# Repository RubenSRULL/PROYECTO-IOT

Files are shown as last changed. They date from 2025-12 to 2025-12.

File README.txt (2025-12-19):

Rubén Sahuquillo Redondo

Estructura del proyecto:
- Carpeta src: contiene el código desarrollado en Python
- Carpeta esp32: contiene los códigos de las ESP32
- Carpeta fig: contiene las figuras y esquemas desarrollados
- Carpeta cad: contiene el esquema del circuito
- Carpeta frizting: contiene el esquema electrónico elaborado en Fritzing

Enlace al repositorio con todo el proyecto: https://github.com/RubenSRULL/PROYECTO-IOT.git

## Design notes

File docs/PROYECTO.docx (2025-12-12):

# PROYECYO IOT:

# CONTROL DE UNA BOMBA DE DESPLAZAMIENTO POSITIVO EN UN SISTEMA DE TRASIEGO DE CRUDO Y COMBUSTIBLES

Rubén Sahuquillo Redondo

alu0101387451@ull.edu.es

Curso 2025 / 2026

# 1. INTRODUCCIÓN

## 1.1. INTRODUCCIÓN

- Este proyecto propone el diseño de un sistema para el control de una bomba de desplazamiento positivo utilizada en el trasiego de combustibles, accionada por un motor trifásico de corriente alterna.
- En este tipo de instalaciones, el arranque del motor se realiza normalmente mediante el método estrella–triángulo. Sin embargo, la conmutación suele ejecutarse por temporización fija, lo que no siempre coincide con la velocidad real del motor ni con las condiciones hidráulicas del sistema. Esta situación puede generar sobrecorrientes, golpes de presión y arranques ineficientes, especialmente cuando la demanda de caudal o presión varía.
- Para resolver este problema, el proyecto incorpora un sensor Hall que mide la velocidad del motor en tiempo real, determinando el momento óptimo para la transición de estrella a triángulo. Además, el sistema cuenta con conectividad IoT, lo que permite monitoreo, registro y supervisión remota, mejorando la seguridad y eficiencia operativa del trasiego de combustibles.

## 1.2. SISTEMA PROPUESTO

- El sistema propuesto consiste en un controlador electrónico, integrado en el microcontrolador ESP 32 WROOM 32, encargado de gestionar el arranque del motor. Durante la puesta en marcha, el sistema de sensado (conformado por el microcontrolador WEMOS D1 R32 y un sensor de efecto Hall) mide la velocidad del eje y envía los datos al microcontrolador de control. Cuando el motor alcanza una velocidad predefinida (un 80% de su velocidad nominal), el controlador activa la conmutación del contacto estrella al contacto triángulo.
- Además, el sistema incorpora conectividad IoT que permite:
  - Monitorizar en tiempo real la velocidad del motor y el estado del arranque
  - Detener y cambiar el sentido de giro de la bomba en cualquier instante

## 1.3. OBJETIVOS

- Objetivo general
  - Implementar un sistema de arranque inteligente para un motor AC que realice la conmutación estrella–triángulo basándose en la velocidad real del motor, utilizando un sensor Hall e integración IoT.
- Objetivos específicos
  - Medir la velocidad del motor durante el arranque mediante un sensor Hall.
  - Integrar el sistema a una plataforma IoT que permita un control efectivo

## 1.4. ALCANCE

- En base a los objetivos y al Proyecto propuesto, el alcance de este proyecto incluye:
  - Implementación y programación del sistema de medición de velocidad mediante sensor de efecto Hall.
  - Desarrollo del controlador encargado de gestionar la conmutación estrella–triángulo en el arranque, parada y cambio de sentido de giro
  - Integración básica con una plataforma IoT para visualización de datos y control de arranque
- El proyecto no implementa un lazo de control cerrado para la regulación de velocidad

# 2. MARCO TEÓRICO

## 2.1. BOMBA DE DESPLAZAMIENTO POSITIVO

- Una bomba de desplazamiento positivo (DP) es un tipo de bomba que traslada un volumen fijo de fluido (generalmente fluidos viscosos) en cada ciclo o rotación, independientemente de la presión del sistema, generando un caudal constante. Algunos tipos de bombas DP se muestran en la figura
- Estas bombas funcionan capturando el fluido en un compartimento cerrado y desplazándolo hacia la salida mediante el movimiento de elementos mecánicos como engranajes, lóbulos, tornillos, pistones o diafragmas.
- Estas bombas se caracterizan por:
  - Manejar un caudal constante, aunque varíe la presión del sistema.
  - Capacidad de manejar fluidos viscosos, abrasivos o cargados de sólidos.
  - Algunas diseñadas para flujo reversible, permitiendo invertir la dirección del líquido cuando el proceso lo requiere.

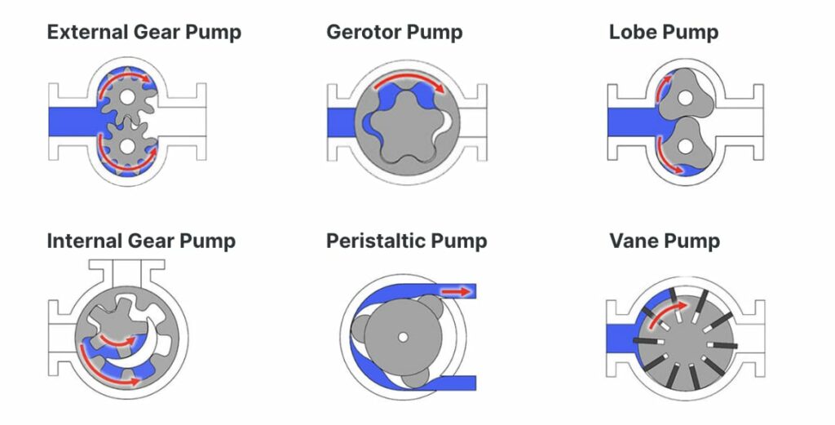
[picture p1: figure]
Positive Displacement Pump - what is positive displacement pump - Vacculex

Ilustración 1: Algunos tipos y mecanismos comunes empleados en bombas de desplazamiento positivo

## 2.2. MOTOR DE INDUCCIÓN TRIFÁSICO: JAULA DE ARDILLA

- Un motor de inducción trifásico es una máquina eléctrica rotativa ampliamente utilizada en aplicaciones industriales debido a su robustez, bajo mantenimiento y buena relación costo-prestaciones.
- Su funcionamiento se basa en el principio de inducción electromagnética: al aplicar un sistema trifásico de tensiones en el estator, se genera un campo magnético giratorio que induce corrientes en el rotor, produciendo el par motor.
- La velocidad del motor depende de la frecuencia de la red y del número de polos del estator. Al tratarse de una máquina asíncrona, el rotor gira a una velocidad ligeramente inferior a la velocidad síncrona
- Estos motores deben arrancar de forma controlada para evitar sobrecorrientes y esfuerzos mecánicos, especialmente cuando la carga hidráulica es variable.

## 2.3. ARRANQUE ESTRELLA - TRIÁNGULO

- El arranque estrella–triángulo es un método convencional para reducir la corriente inicial de los motores trifásicos. Consiste en conectar los devanados del estator inicialmente en configuración estrella, lo que reduce la tensión aplicada a cada fase y, por tanto, la corriente y el par motor. Después de un intervalo determinado, los devanados se reconectan en configuración triángulo, permitiendo que el motor reciba la tensión nominal y alcance su par y velocidad de operación.
- En este proyecto, la conmutación se realiza según la velocidad real del motor, eliminando la dependencia del tiempo y optimizando el proceso.

## 2.4. SENSOR HALL

- Un sensor Hall es un dispositivo que detecta la presencia de un campo magnético y genera una señal eléctrica proporcional. Su funcionamiento se basa en el efecto Hall, fenómeno que produce una variación de tensión cuando un conductor atravesado por corriente se expone a un campo magnético perpendicular (este efecto se muestra en la figura 2)
- Cuando se coloca un imán adherido al eje del motor, el sensor detecta cada paso del imán y produce un pulso. Contando estos pulsos en un intervalo conocido, es posible calcular la velocidad de giro.
- Los sensores Hall son adecuados para entornos industriales debido a su fiabilidad, su bajo consumo y su capacidad para medir sin contacto mecánico.
- En este proyecto se emplea este sensor para determinar el instante preciso en el que el motor alcanza la velocidad necesaria para realizar la transición de estrella a triángulo.

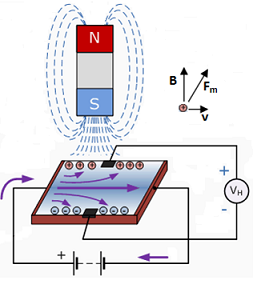
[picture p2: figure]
Electromagnetismo. Efecto Hall

Ilustración 2: Efecto Hall

# 3. DESARROLLO

## 3.1. MEDICIÓN DE VELOCIDADES. VALIDACIÓN

- La arquitectura implementada para la medición de velocidades consiste en:
  - Acoplamiento de un imán de neodimio al eje del motor de inducción.
  - Colocación del sensor hall en posición óptima, es decir, aquella posición que permita la detección del campo magnético generado por el imán sin comprometer las lecturas o integridad del sensor
  - Activar lectura de interrupciones en un pin del Wemos D1 R32 por un tiempo determinado. Cada vez que el imán pase frente al sensor hall, este generará un pulso, produciendo una interrupción.
  - En ficha interrupción se realizará el conteo de pulsos detectado (o equivalentemente, contar cuántas veces pasa el imán frente al sensor). Contar los pulsos producidos en un tiempo determinado (1 segundo) y dividir entre 2 (ya que se producen 2 pulsos por revolución)
  - Dividir número de pulsos entre tiempo de medición

ω=(revoluciones)/(tiempo) [Hz]

  - Reiniciar contador e interrupciones para permitir la obtención de nuevas mediciones
- Las mediciones de velocidad fueron validadas empleando el controlador de velocidad ATV320 (figura 3). Tanto con el controlador ATV320 con el sensor hall se obtuvieron lecturas similares:

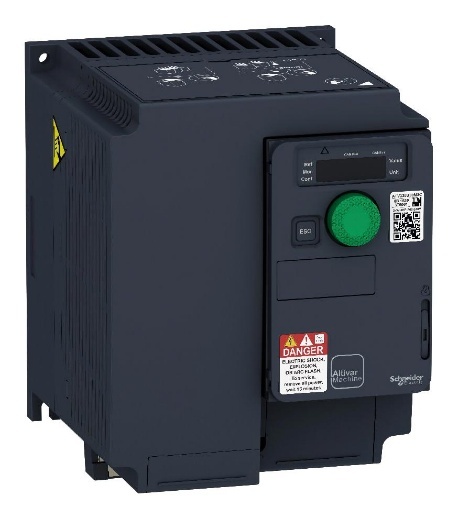
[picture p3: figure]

Ilustración 3: Controlador de velocidad ATV320, empleado para validar el sistema de medición

## 3.2. LÓGICA DE CONMUTACIÓN

### 3.2.1. CIRCUITO DE POTENCIA

- El circuito de potencia que alimenta al motor de inducción trifásico permite el cambio de sentido de giro (gestionado por los contactores KM1 Y KM2) además de la conmutación estrella – triángulo (gestionado por los contactores KM3 y KM4). Se incluye un guardamotor y un fusible como elementos de seguridad (ver figura 4)

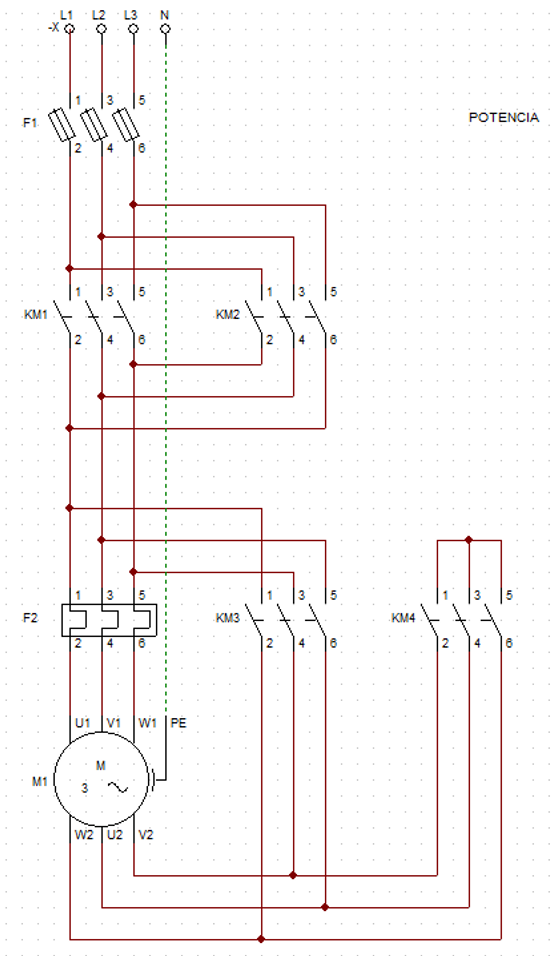
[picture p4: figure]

Ilustración 4: Circuito eléctrico de potencia

### 3.2.2. CIRCUITOS DE CONTROL

- El circuito que permite el accionamiento de los diferentes contactores de control del sistema está conformado por 4 relés que activan los diferentes contactores (esquema mostrado en la figura 5):
  - Los relés 1 y 2 activan las bobinas de los contactores KM1 y KM2 respectivamente con enclavamiento eléctrico, impidiendo que ambos contactores puedan estar activos a la vez. Este mecanismo permite seleccionar únicamente un sentido de giro
  - Los relés 3 y 4 activan las bobinas de los contactores KM3 y KM4 respectivamente con enclavamiento eléctrico, impidiendo que ambos contactores puedan estar activos a la vez. Este mecanismo permite configurar únicamente la conexión estrella o triángulo.
  - Como dispositivos de protección eléctrica se incluyen un fusible y un térmico F1 y F2. Además, como dispositivo de paro y control manual, se incluye un pulsador normalmente cerrado. En caso de ser presionado, abre el circuito de control, impidiendo el paso de corriente eléctrica a los contactores, deteniendo el motor. Como señal luminosa, se incluye un led de estado que indica la presencia de tensión en el sistema

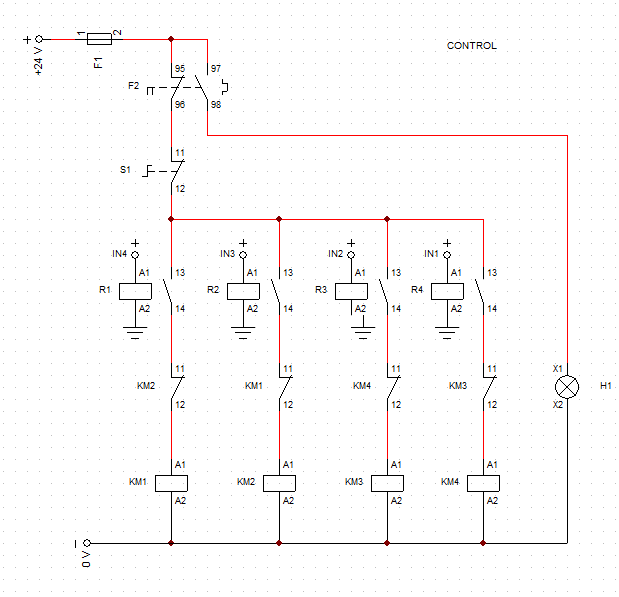
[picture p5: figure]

Ilustración 5: Circuito eléctrico de control

### 3.2.3. ELECTRÓNICA: SENSORES Y RELÉS

- El circuito electrónico (figura 6) consiste en 2 partes diferencias:
  - Circuito del sistema de sensado, conformado por:
    - Microcontrolador Wemos D1 R32, encargado de la medición de velocidad de rotación y publicación de esta por MQTT.
    - Módulo KY – 035 que integra un sensor Hall, empleado como sensor de velocidad
    - Condensador cerámico de 100 μF, conectado entre la señal de pulsos y tierra. Su finalidad es, junto a un filtro digital también programado, filtrar el ruido de lectura entre pulsos consecutivos
    - Pantalla LCD Hitachi 16x2 con módulo I2C
    - Batería de 9 V
  - Circuito del sistema de control, conformado por:
    - Microcontrolador ESP32 WROOM 32, encargado de alojar el servidor web, controlar tanto la secuencia de arranque como el sentido de giro del motor y de la lectura de velocidades publicadas
    - Módulo de control de relés AVR PIC, empleados para la activación de contactores

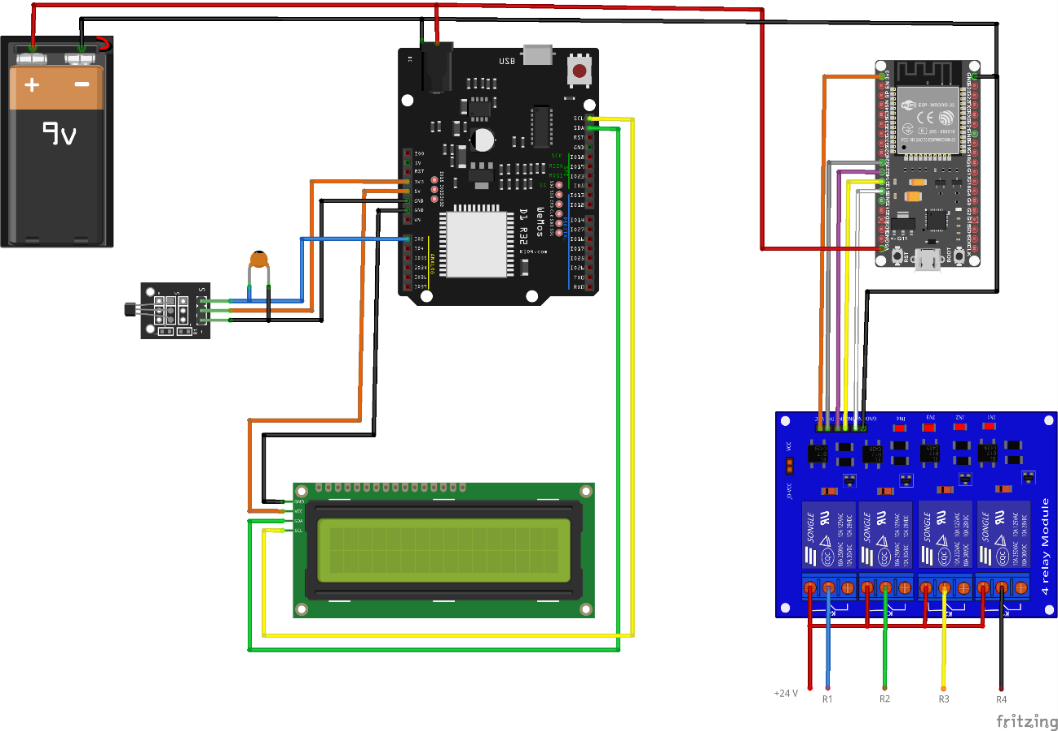
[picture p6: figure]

Ilustración 6: Circuito eléctrico de control de relés y sensado (elaborado en fritzing)

## 3.3. INTERFAZ WEB

- La interfaz web desarrollada actúa como el punto central de supervisión y control del sistema, permitiendo al usuario gestionar el funcionamiento del motor de manera remota desde cualquier dispositivo conectado a la misma red. Una vista de esta interfaz web se muestra en la figura 7.
- En primer lugar, la interfaz permite seleccionar el sentido de giro de la bomba (giro horario o antihorario) mediante comandos enviados al microcontrolador a través del servidor web integrado. También incorpora una opción de parada inmediata, asegurando que el motor pueda ser detenido en cualquier momento, incluso durante el proceso de arranque o transición entre configuraciones.
- La interfaz muestra información en tiempo real sobre la velocidad de rotación del motor en hercios (Hz). Esto permite al usuario conocer en todo momento el comportamiento dinámico del motor.
- La interfaz también refleja el estado actual del sistema, indicando si el motor se encuentra detenido, en giro horario, en giro antihorario o en fase de arranque. De esta forma, el operador puede supervisar desde una única vista tanto la condición mecánica del motor como el progreso del algoritmo de conmutación.

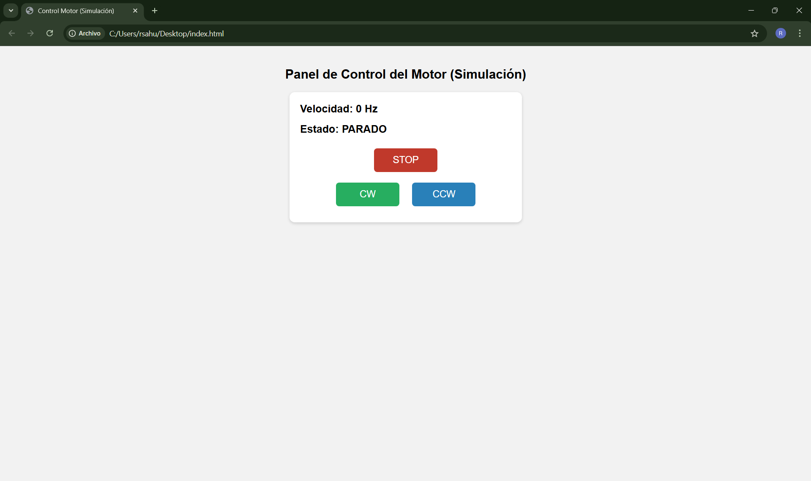
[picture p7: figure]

Ilustración 7: Vista de la interfaz web desarrollada

## 3.4. COMUNICACIONES MQTT

- El sistema utiliza el protocolo MQTT (Message Queuing Telemetry Transport) para intercambiar información entre los dos dispositivos principales:
  - WEMOS D1 R32 → encargado de leer el sensor Hall y enviar las RPM.
  - ESP32 WROOM 32 → encargado de procesar esa información y controlar los relés.
- Toda la comunicación está centralizada en un broker MQTT, alojado en el PC, que actúa como intermediario entre publicadores y suscriptores.
- MQTT funciona mediante tópicos, que son “canales” por donde se envían o reciben mensajes. Cada dispositivo puede ser:
  - Publicador (publisher) → Envía datos a un tópico.
  - Suscriptor (subscriber) → Recibe datos de un tópico

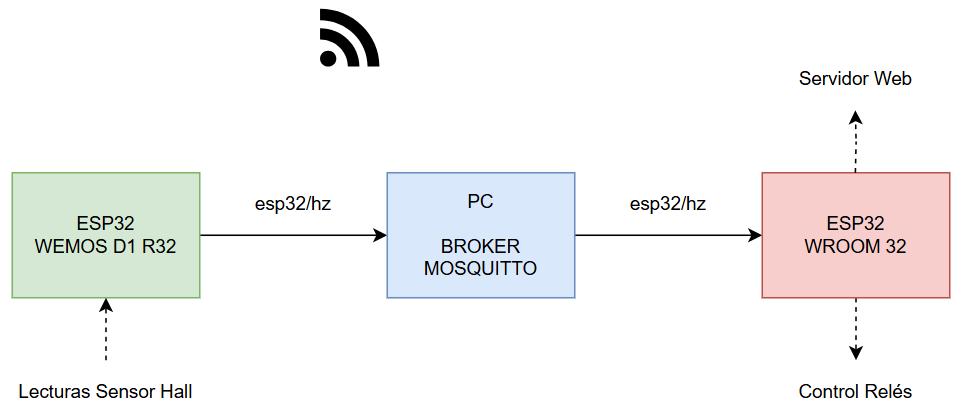
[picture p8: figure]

Ilustración 8: Esquema de comunicaciones MQTT implementado

# 4. CÓDIGOS DESARROLLADOS

## 4.1. CÓDIGO DEL MICROCONTROLADOR DE SENSADO (WEMOS D1 R32)

- Función de setup(): Esta función inicializa el programa. Se encarga de:
  - Inicializar el módulo WiFi.
  - Inicializar la comunicación MQTT.
  - Configurar interrupción para leer velocidad

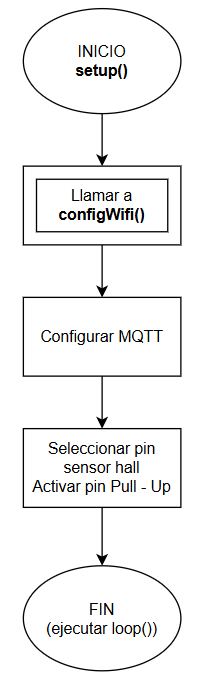
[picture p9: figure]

Ilustración 9: Flujograma del setup()

- Función de loop(): esta función se encarga de leer y calcular la velocidad de rotación del motor de forma periódica. Se encarga de:
  - Reestablecer la comunicación MQTT si esta se ha perdido
  - Mantener abierta la comunicación MQTT
  - Medir la velocidad de rotación del motor
  - Publicar mediciones por MQTT al tópico esp32/hz

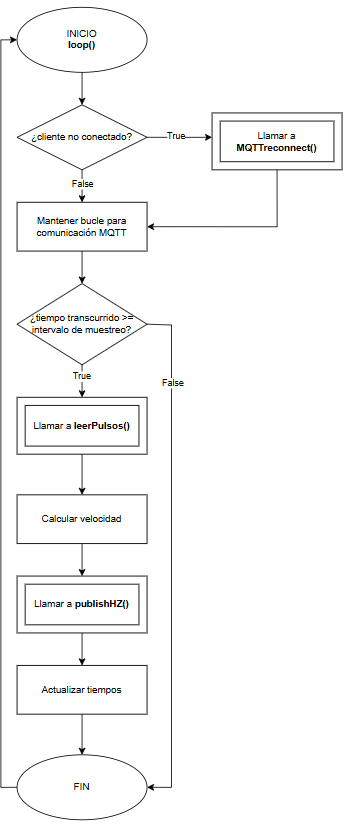
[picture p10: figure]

Ilustración 10: Flujograma del loop()

- Funciones llamadas en el setup():
  - Función configWifi(): Esta función permite establecer conexión WiFi y coenctarse a la red. Se encarga de:
    - Configurar comunicación Wifi en modo estación
    - Iniciar la conexión Wifi

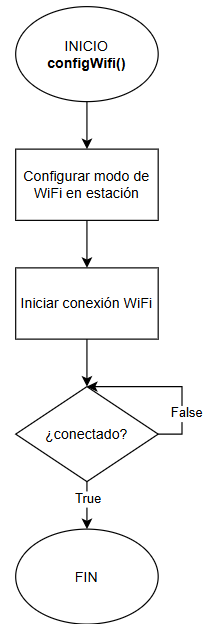
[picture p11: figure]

Ilustración 11: Flujograma función configWifi()

- Funciones llamadas en el loop()
  - Función leerPulsos(): Esta función permite leer los pulsos contabilizados de forma segura además de reiniciar el contador de pulsos, permitiendo obtener una nueva medición de velocidad

Ilustración 12: Flujograma función leerPulsos()

  - Función publishHZ(): Esta función permite publicar la velocidad calculada al tópico esp32/hz

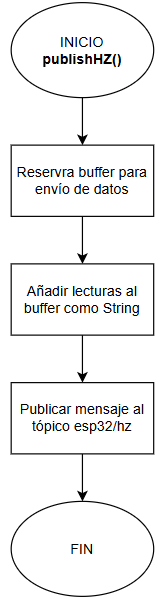
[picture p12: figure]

Ilustración 13: Función para publicar velocidad leída en hercios, publishHZ()

  - Función MQTTreconnect(): Esta función permite reconectar la conexión con el broker MQTT y/o wifi si alguna de estas se pierde

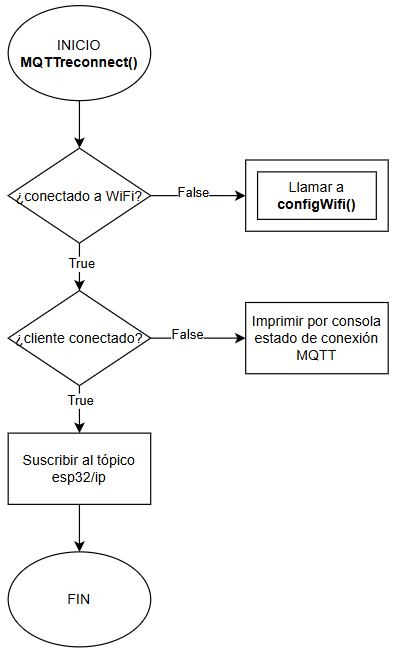
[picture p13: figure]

Ilustración 14: Función para reconectar con bróker MQTT, MQTTreconnect()

## 4.2. CÓDIGO DEL MICROCONTROLADOR DE CONTROL (ESP32 WROOM 32)

- Función setup(): Esta función inicializa el programa. Se encarga de:
  - Inicializar el módulo WiFi.
  - Inicializar la comunicación MQTT.
  - Inicializar servidor web

Ilustración 15: Flujograma del setup()

- Función loop(): esta función permite mantener activo el servidor web, así como el control del motor trifásico por medio de una máquina de estados (arranque, parada y sentido de giro). Se encarga de:
  - Reestablecer la comunicación MQTT si esta se ha perdido
  - Mantener abierta la comunicación MQTT
  - Mantener activo el servidor web
  - En función del estado actual del sistema, ejecutar la acción de control oportuna

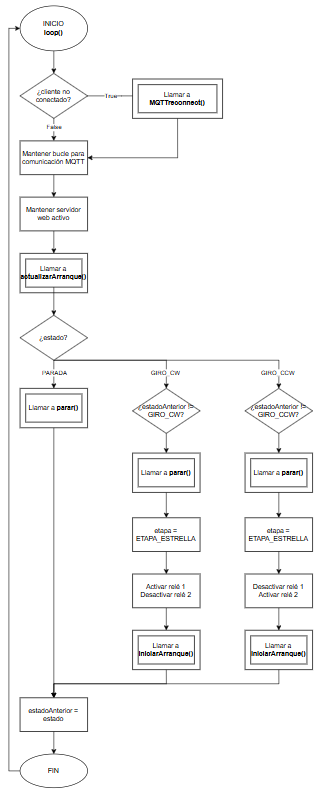
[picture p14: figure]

Ilustración 16: Flujograma del loop()

- Funciones llamadas en el setup()
  - Función configWifi(): Esta función permite establecer conexión Wifi y conectarse a la red. Se encarga de:
    - Configurar comunicación Wifi en modo estación
    - Iniciar la conexión Wifi

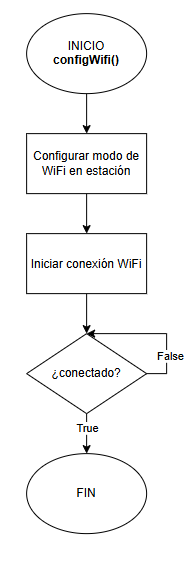
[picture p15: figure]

Ilustración 17: Flujograma de la función configWifi()

- Funciones llamadas en el loop()
  - Función MQTTreconnect(): Esta función permite reestablecer la conexión con el broker MQTT y/o Wifi si alguna de estas se pierde

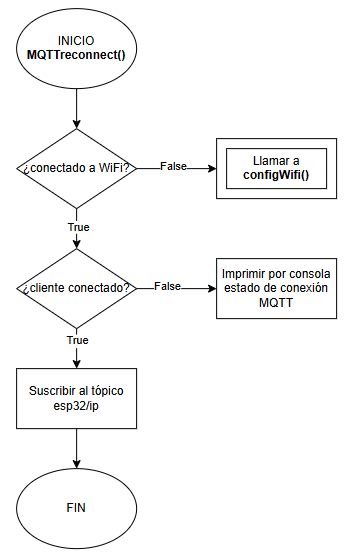
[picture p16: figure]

Ilustración 18: Flujograma de la función MQTTreconnect()

  - Función parar(): Esta función permite detener completamente el motor
  - Función iniciarArranque(): Esta función inicia la secuencia de arranque, realizando la conexión en estrella hasta que la velocidad leída sea superior al umbral establecido
  - Función actualizarArranque(): Esta función permite realizar la conmutación a triángulo una vez la velocidad leída es la adecuada

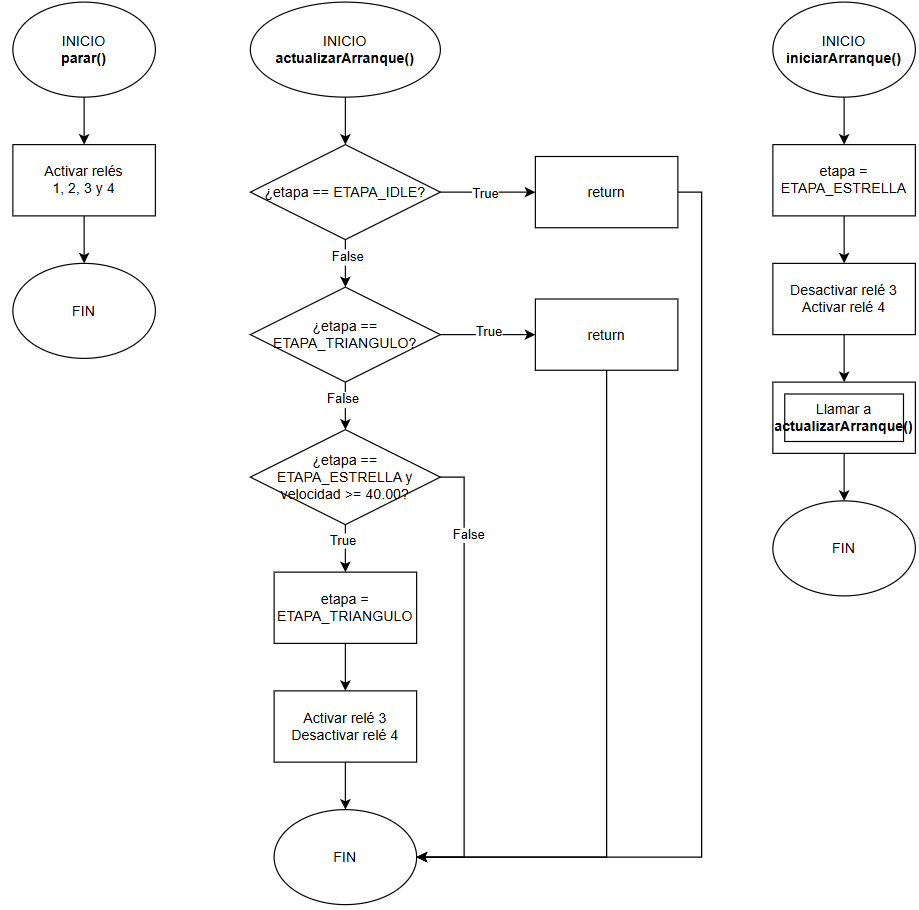
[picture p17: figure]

Ilustración 19: Flujogramas de las funciones parar(), actualizarArranque(), iniciarArranque()

- Función para generar página web generarPagina(): esta función define la interfaz web. Permite:
  - Definir el código HTML dentro de una variable String
  - Modificar textos HTML en función del estado actual del sistema y velocidad recibida por MQTT

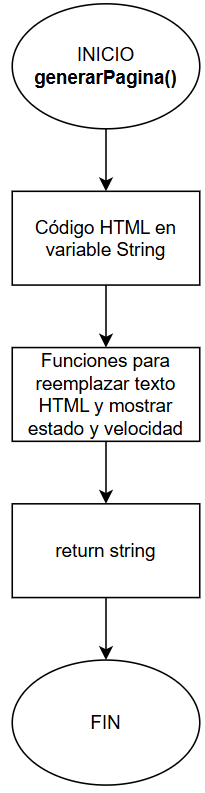
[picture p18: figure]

Ilustración 20: Flujograma con la función para generar la página web generarPagina()

- Función de Callback MQTT → callback(): Esta función es ejecutada cada vez que se recibe un mensaje por MQTT. Permite recibir las velocidades leídas desde el microcontrolador encargado de la adquisición de datos

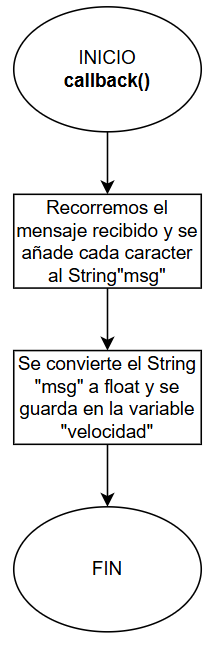
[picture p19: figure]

Ilustración 21: Función de callback, callback(). Se ejecuta cada vez que se recibe un mensaje MQTT

## 4.3. CÓDIGO PARA ARRANCAR BROKER MOSQUITTO

- Este script permite inicializar el bróker Mosquitto y cargar el fichero de configuración (.conf), evitando introducir comandos en consola, facilitando su inicialización
1. Se importan las librerías siguientes:
  a. os: facilita el manejo de ficheros
  b. subprocess: permite ejecutar comandos en consola desde el script
  c. time: permite el manejo de funciones de tiempo
2. Se indican las rutas tanto del ejecutable Mosquitto (.exe) y el fichero de configuración (.conf)
3. En “__main__” se llama a la función iniciar_broker()
4. Función iniciar_broker(): esta función arranca el proceso mosquitto.exe siempre que no esté activo en la lista de procesos activos. En caso de estar activo, mostrará un mensaje de confirmación y en caso de ocurrir un error, los mostrará por pantalla

import os

import subprocess

import time

mosquitto_path = r"C:\Program Files\mosquitto\mosquitto.exe"

mosquitto_conf = r"C:\Program Files\mosquitto\mosquitto.conf"

def iniciar_broker():

try:

procesos = os.popen('tasklist').read().lower()

if "mosquitto.exe" not in procesos:

subprocess.Popen(

f'"{mosquitto_path}" -v -c "{mosquitto_conf}"',

shell=True,

stdout=subprocess.DEVNULL,

stderr=subprocess.DEVNULL

)

print("Broker Mosquitto iniciado en segundo plano.")

time.sleep(3)

else:

print("Broker Mosquitto ya está ejecutándose.")

except Exception as e:

print(f"Error al iniciar el broker: {e}")

if __name__ == '__main__':

iniciar_broker()

# 5. ANEXOS

## 5.1. MICROCONTROLADOR: ESP32 – WROOM – 32

https://descubrearduino.com/esp32-modulo-esp32-wroom-gpio-pinout/

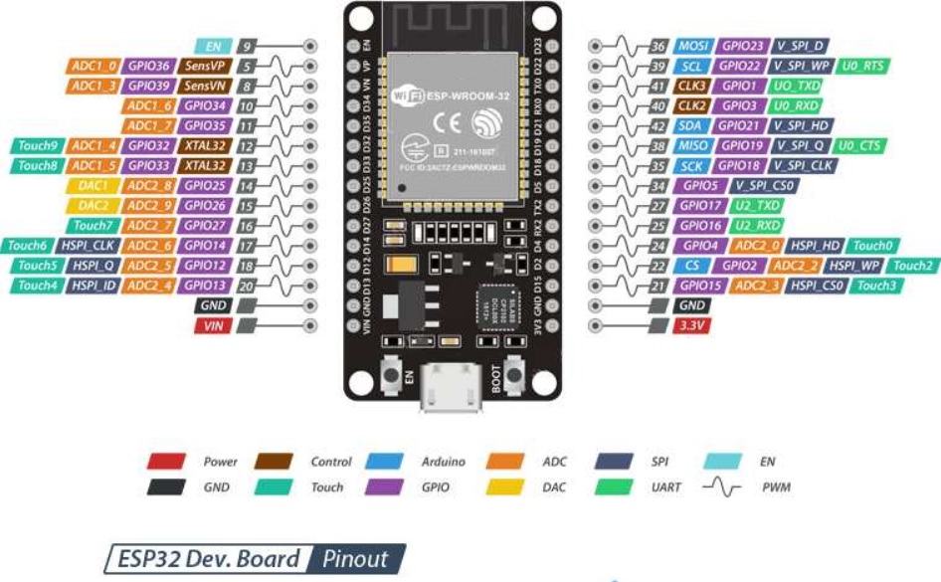
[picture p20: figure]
ESP32, módulo ESP32-WROOM GPIO Pinout - Descubrearduino.com

Ilustración 22: ESP – WROOM - 32

## 4.2. MICROCONTROLADOR: WEMOS D1 R32

https://doc.riot-os.org/group__boards__esp32__wemos__d1__r32.html

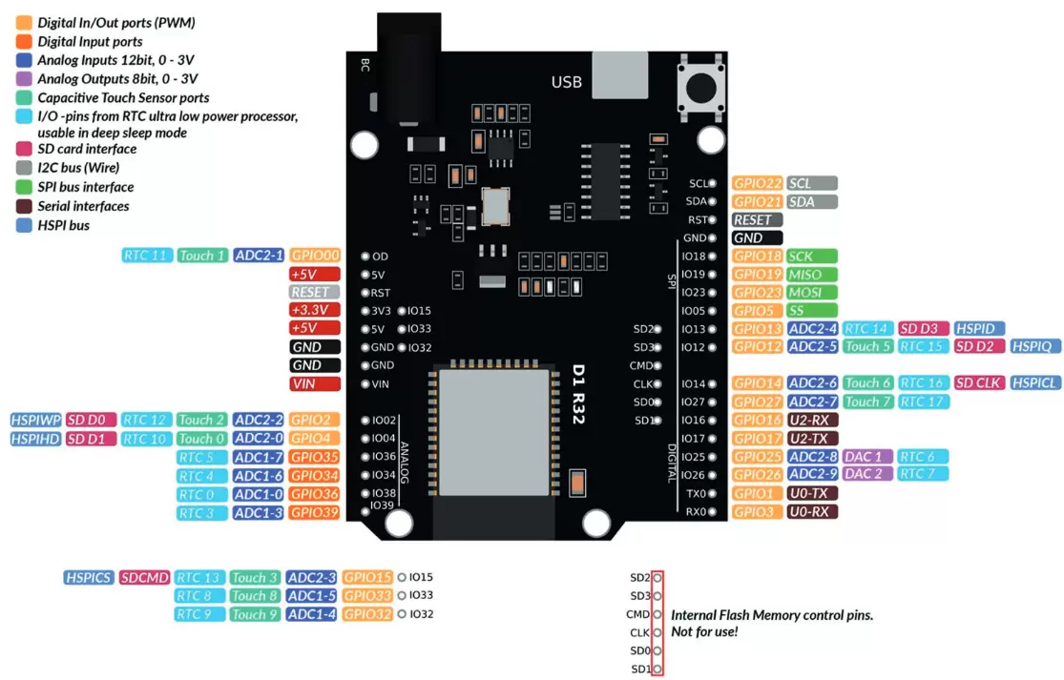
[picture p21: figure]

Ilustración 23: WEMOS D1 R32

## 4.3. MÓDULO SENSOR HALL: KY – 035

https://components101.com/sensors/ky035-hall-magnetic-sensor-module-pinout-features-datasheet-working-applications-alternative

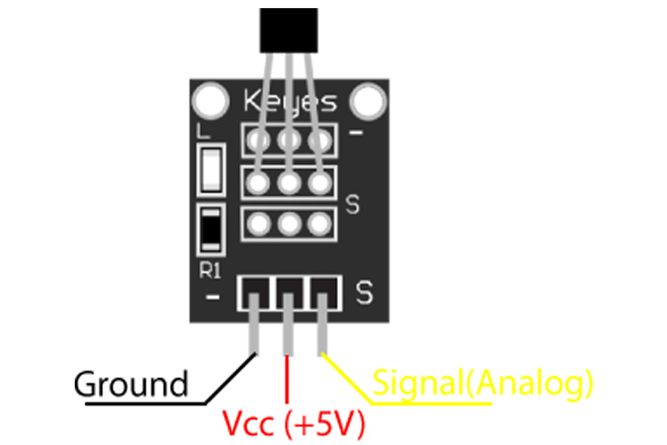
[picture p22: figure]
KY-035 Hall Magnetic Sensor Module Pinout, Features, Datasheet, Working, Alternative, Application

Ilustración 24: Módulo KY-085, sensor Hall

## 4.4. MÓDULOS DE 4 RELÉS: AVR DSP PIC

chrome-extension://efaidnbmnnnibpcajpcglclefindmkaj/https://mm.digikey.com/Volume0/opasdata/d220001/medias/docus/5773/TS0011%20DATASHEET.pdf

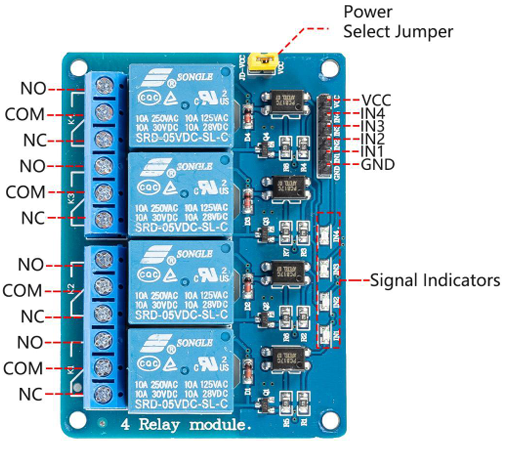
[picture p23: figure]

Ilustración 25: Módulo de relés AVR DSP PIC

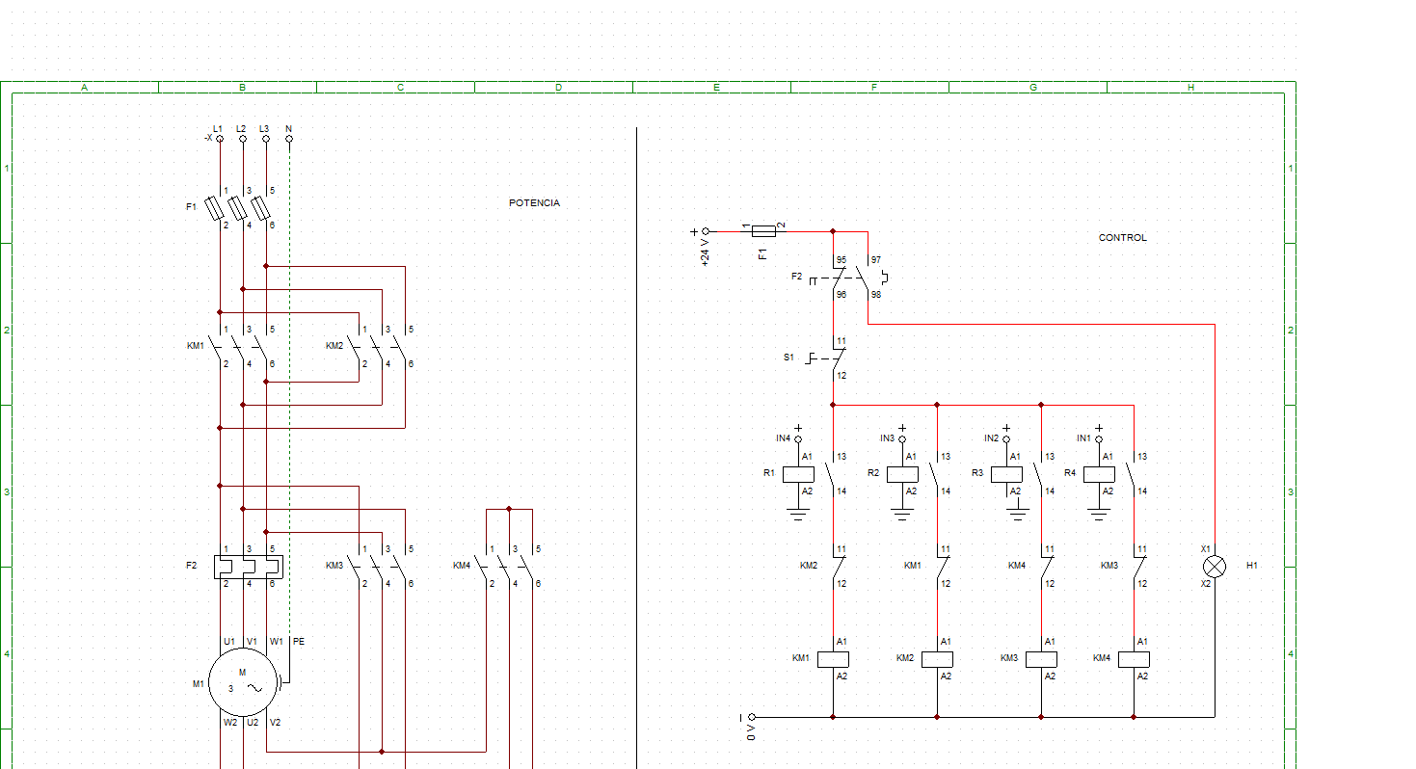
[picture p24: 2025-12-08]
fig/ESQUEMA PROYECTO IOT.bmp

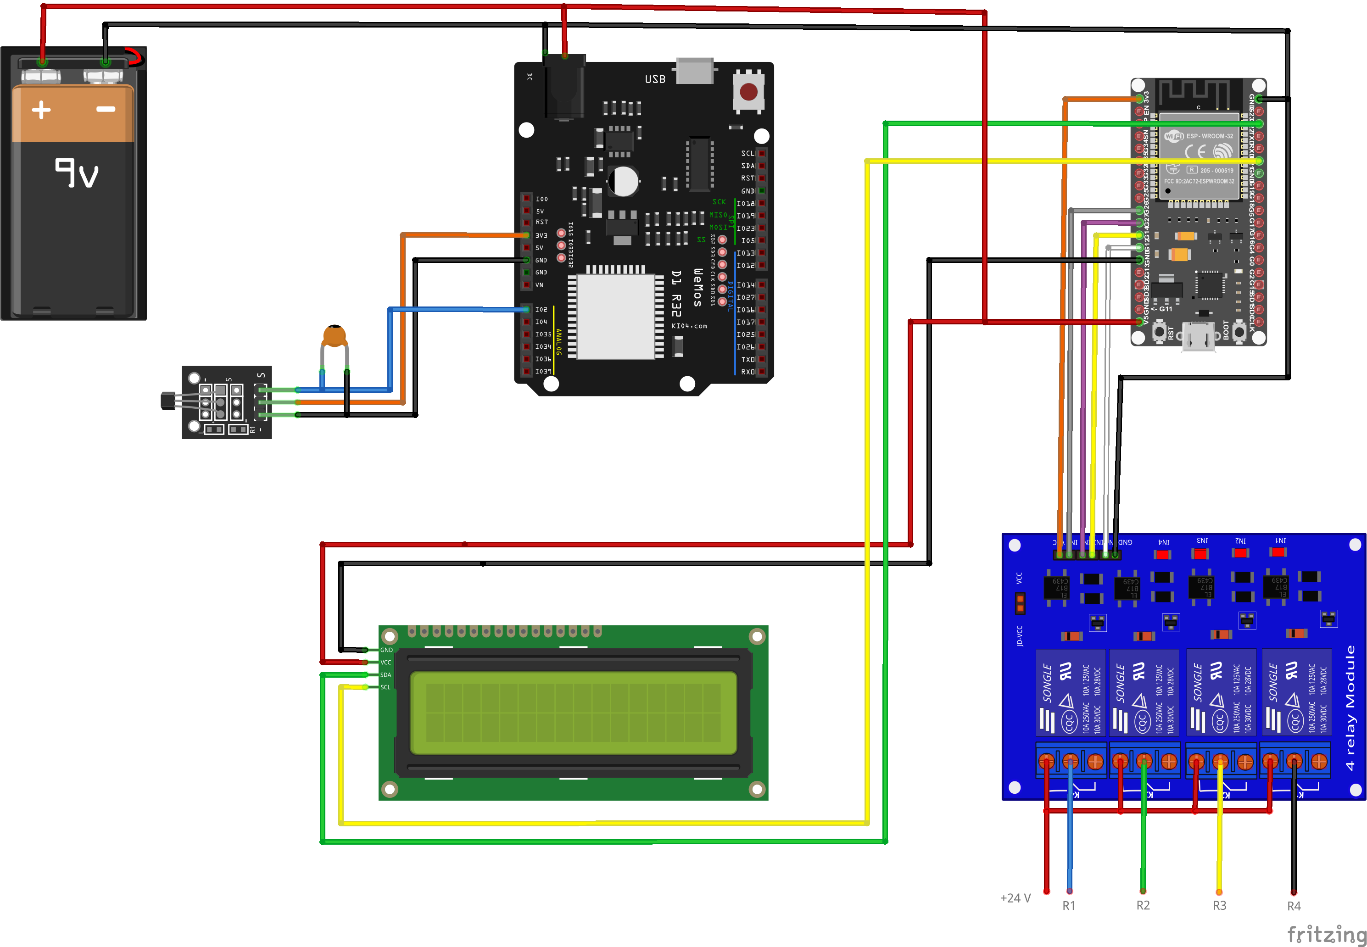
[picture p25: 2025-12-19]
fritzing/esquema_proyecto.png

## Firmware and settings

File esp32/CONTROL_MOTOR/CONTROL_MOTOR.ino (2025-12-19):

//AUTOR: Ruben Sahuquillo Redondo
//ASIGNATURA: Internet de las Cosas
//CÓDIGO uC CONTROL


// --- LIBRERÍAS --- //
#include <WiFi.h>
#include <WebServer.h>
#include <PubSubClient.h>
#include <LiquidCrystal_I2C.h>

// --- ESTADOS MOTOR --- //
#define PARADA     0
#define GIRO_CW    1
#define GIRO_CCW   2

int estado = PARADA;
int estadoAnterior = PARADA;

// --- ETAPAS DE ARRANQUE --- //
#define ETAPA_IDLE        0
#define ETAPA_ESTRELLA    1
#define ETAPA_TRIANGULO   2

int etapa = ETAPA_IDLE;
unsigned long etapaStart = 0;

// --- PINES RELES --- //
const int rele1 = 26;
const int rele2 = 27;
const int rele3 = 12;
const int rele4 = 14;

// --- WIFI --- //
const char* ssid = "OPPO A53";
const char* password = "611b10a883c5";
const char* mqtt_server = "10.74.94.63";

// --- OBJETOS --- //
WiFiClient espClient;
PubSubClient client(espClient);
WebServer server(80);
LiquidCrystal_I2C lcd(0x27,16,2);

// --- VELOCIDAD --- //
float velocidadNominal = 50.00;
float velocidad = 0.0;

// --- CALLBACK MQTT --- //
void callback(char* topic, byte* payload, unsigned int length) {
  Serial.print("Mensaje recibido en: ");
  Serial.println(topic);
  String msg = "";
  for (int i = 0; i < length; i++) msg += (char)payload[i];
  velocidad = msg.toFloat();

  Serial.print("Velocidad actualizada: ");
  Serial.println(velocidad);

  mostrarVelocidadLCD();
}


// --- WIFI --- //
void configWifi() {
  WiFi.mode(WIFI_STA);
  WiFi.begin(ssid, password);
  Serial.print("Conectando");
  while (WiFi.status() != WL_CONNECTED) {
    delay(500);
    Serial.print(".");
  }
  Serial.println("\nWiFi conectado");
  Serial.print("IP: ");
  Serial.println(WiFi.localIP());

  lcd.clear();
  lcd.setCursor(0, 0);
  lcd.print("IP:");
  lcd.print(WiFi.localIP());
}

// --- MOSTRAR VELOCIDAD --- //
void mostrarVelocidadLCD() {
  lcd.setCursor(0, 1);
  lcd.print("Vel: ");
  lcd.print(velocidad, 2);
  lcd.print(" Hz   ");
}


// --- MQTT --- //
void reconnect() {
  while (!client.connected()) {
    Serial.print("Intentando conexión MQTT... ");
    if (client.connect("ESP32_MOTOR")) {
      Serial.println("Conectado");
      client.subscribe("esp32/hz");  
    } else {
      Serial.print("Error: ");
      Serial.println(client.state());
      delay(2000);
    }
  }
}

// --- WEB PAGE --- //
String generarPagina() {
  String h = R"rawliteral(
<!DOCTYPE html>
<html>
<head>
<meta charset="UTF-8">
<meta name='viewport' content='width=device-width, initial-scale=1.0'>
<title>Control Motor</title>
<style>
body { 
    font-family: Arial; 
    background:#f2f2f2; 
    margin:0; 
    padding:20px; 
}
h2 { 
    text-align:center; 
    margin-bottom:20px; 
}
.panel { 
    background:white; 
    padding:20px; 
    border-radius:10px;
    box-shadow:0 2px 6px rgba(0,0,0,0.15); 
    max-width:400px; 
    margin:auto; 
}
.estado { 
    font-size:20px; 
    margin-bottom:15px; 
    font-weight:bold; 
}
button { 
    width:120px; 
    height:45px; 
    margin:10px; 
    font-size:18px;
    border:none; 
    border-radius:6px; 
    cursor:pointer; 
}
.stop { background:#c0392b; color:white; }
.cw   { background:#27ae60; color:white; }
.ccw  { background:#2980b9; color:white; }
</style>
</head>
<body>
<h2>Panel de Control del Motor</h2>
<div class="panel">
    <div class="estado">Velocidad: <span id="vel">%VEL%</span> Hz</div>
    <div class="estado">Estado: <span id="estado">%ESTADO%</span></div>
    <div style="text-align:center;">
        <button class="stop" onclick="accion('stop')">STOP</button><br>
        <button class="cw" onclick="accion('cw')">CW</button>
        <button class="ccw" onclick="accion('ccw')">CCW</button>
    </div>
</div>
<script>
function accion(cmd) {
    fetch('/' + cmd);
}
setInterval(() => {
    fetch('/datos')
    .then(r => r.json())
    .then(d => {
        document.getElementById("vel").innerText = d.velocidad;
        document.getElementById("estado").innerText = d.estado;
    });
}, 1000);
</script>
</body>
</html>
)rawliteral";
  h.replace("%VEL%", String(velocidad, 2));
  if (estado == PARADA){
    h.replace("%ESTADO%", "PARADO");
  }
  else if (estado == GIRO_CW) {
    h.replace("%ESTADO%", "GIRO CW");
  }
  else if (estado == GIRO_CCW){
    h.replace("%ESTADO%", "GIRO CCW");
  }
  return h;
}

// --- MANTENER HTML --- //
void handleRoot() {
  server.send(200, "text/html", generarPagina());
}

// --- FUNCION ENVIAR DATOS DE ESTADO Y VELOCIDAD A SERVIDOR WEB MEDIANTE FICHERO .json --- //
void enviarDatos() {
  String json = "{";
  json += "\"velocidad\":\"" + String(velocidad, 2) + "\",";
  json += "\"estado\":\"";
  if (estado == PARADA) json += "PARADO";
  else if (estado == GIRO_CW) json += "GIRO CW";
  else if (estado == GIRO_CCW) json += "GIRO CCW";
  json += "\"}";
  server.send(200, "application/json", json);
}

// --- FUNCION PARA DETENER MOTOR --- //
void stopMotor() {
  estado = PARADA;
  server.sendHeader("Location", "/");
  server.send(303);
}

// --- FUNCION PARA GIRAR EN SENTIDO ANTIHORARIO --- //
void cwMotor() {
  estado = GIRO_CW;
  server.sendHeader("Location", "/");
  server.send(303);
}

// --- FUNCION PARA GIRAR EN SENTIDO HORARIO --- //
void ccwMotor() {
  estado = GIRO_CCW;
  server.sendHeader("Location", "/");
  server.send(303);
}

// --- ACCIONES MOTOR --- //
void parar() {
  digitalWrite(rele1, HIGH);
  digitalWrite(rele2, HIGH);
  digitalWrite(rele3, HIGH);
  digitalWrite(rele4, HIGH);
}

// --- FUNCION PARA INICIAR ARRANQUE EN ESTRELLA --- //
void iniciarArranque() {
  etapa = ETAPA_ESTRELLA;
  Serial.println("Estrella");
  digitalWrite(rele3, LOW);  
  digitalWrite(rele4, HIGH);
  actualizarArranque();
}

// --- FUNCION PARA ACTUALIZAR ARRANQUE Y CONMUTAR A TRIÁNGULO --- //
void actualizarArranque() {
  if (etapa == ETAPA_IDLE) return;
  if (etapa == ETAPA_TRIANGULO) return;
  if ((etapa == ETAPA_ESTRELLA) && (velocidad >= 3.00)) {
    etapa = ETAPA_TRIANGULO;
    digitalWrite(rele3, HIGH);
    digitalWrite(rele4, LOW);
  }
}

// --- SETUP --- //
void setup() {
  Serial.begin(115200);
  pinMode(rele1, OUTPUT);
  pinMode(rele2, OUTPUT);
  pinMode(rele3, OUTPUT);
  pinMode(rele4, OUTPUT);
  parar();
  lcd.init();
  lcd.backlight();
  configWifi();
  client.setServer(mqtt_server, 1883);
  client.setCallback(callback);
  server.on("/", handleRoot);
  server.on("/stop", stopMotor);
  server.on("/cw", cwMotor);
  server.on("/ccw", ccwMotor);
  server.on("/datos", enviarDatos);
  server.begin();
  
}

// --- LOOP --- //
void loop() {
  if (!client.connected()){
    reconnect();
  }
  client.loop();
  server.handleClient();
  actualizarArranque();
  if (estado == PARADA) {
    parar();
    etapa = ETAPA_IDLE;
  }
  else if (estado == GIRO_CW) {
    if (estadoAnterior != GIRO_CW) {
      parar();
      etapa = ETAPA_ESTRELLA;
      digitalWrite(rele1, LOW);
      digitalWrite(rele2, HIGH);
      iniciarArranque();
    }
  }
  else if (estado == GIRO_CCW) {
    if (estadoAnterior != GIRO_CCW) {
      parar();
      etapa = ETAPA_ESTRELLA;
      digitalWrite(rele1, HIGH);
      digitalWrite(rele2, LOW);
      iniciarArranque();
    }
  }
  estadoAnterior = estado;
}

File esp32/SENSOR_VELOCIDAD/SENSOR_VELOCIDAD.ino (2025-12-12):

//AUTOR: Ruben Sahuquillo Redondo
//ASIGNATURA: Internet de las Cosas
//CÓDIGO uC SENSORIZACION


// --- LIBRERÍAS --- //
#include <PubSubClient.h>
#include <WiFi.h>

// --- PINES --- //
#define SENSOR_HALL 25

// --- CONFIGURACIÓN --- //
const char* ssid = "OPPO A53";
const char* password = "611b10a883c5";
const char* mqtt_server = "10.74.94.63";

// --- TIEMPOS --- //
const unsigned long SAMPLE_INTERVAL = 1000;
unsigned long lastSample = 0;

// --- CONTADOR DE PULSOS --- //
volatile int contador = 0;
volatile unsigned long lastPulseTime = 0;

// --- OBJETOS --- //
WiFiClient espClient;
PubSubClient client(espClient);

// --- ISR --- //
void IRAM_ATTR pulseISR() {
  unsigned long now = micros();
  if (now - lastPulseTime > 500) {
    contador++;
    lastPulseTime = now;
  }
}

// --- LEER PULSOS --- //
int leerPulsos() {
  noInterrupts();
  int p = contador;
  contador = 0;
  interrupts();
  return p;
}

// --- WIFI --- //
void configWifi() {
  WiFi.mode(WIFI_STA);
  WiFi.begin(ssid, password);
  Serial.print("Conectando");
  while (WiFi.status() != WL_CONNECTED) {
    delay(300);
    Serial.print(".");
  }
  Serial.println("\nWiFi conectado");
}

// --- MQTT --- //
void MQTTreconnect() {
  while (!client.connected()) {
    if (WiFi.status() != WL_CONNECTED){
      configWifi();
    }
    Serial.print("Intentando MQTT... ");
    if (client.connect("ESP32_HallSensor")) {
      Serial.println("OK");
    } else {
      Serial.print("Error: ");
      Serial.println(client.state());
      delay(2000);
    }
  }
}

// --- PUBLICAR HZ --- //
void publishHZ(float vel) {
  char buffer[16];
  snprintf(buffer, sizeof(buffer), "%.0f", vel);
  client.publish("esp32/hz", buffer);
}

// --- SETUP --- //
void setup() {
  Serial.begin(115200);
  configWifi();
  client.setServer(mqtt_server, 1883);
  pinMode(SENSOR_HALL, INPUT_PULLUP);
  attachInterrupt(digitalPinToInterrupt(SENSOR_HALL), pulseISR, FALLING);
  lastSample = millis();
}

// --- LOOP --- //
void loop() {
  if (!client.connected()){
    MQTTreconnect();
  } 
  client.loop();
  unsigned long now = millis();
  if (now - lastSample >= SAMPLE_INTERVAL) {
    float pulsos = float(leerPulsos()) / 2.00;
    publishHZ(pulsos);
    Serial.println(pulsos);
    lastSample = now;
  }
}

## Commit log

2025-12-08 Add esp32 directory
2025-12-19 figuras actualizadas
    [esp32.fzz]
